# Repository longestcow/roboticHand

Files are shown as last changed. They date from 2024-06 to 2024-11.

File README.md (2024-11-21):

# Robotic Hand  
Robotics and Automation 30 major project, a computer-vision controlled robotic hand.  
All 3D parts were modelled with Autodesk Inventor.  

https://github.com/longestcow/roboticHand/assets/83398131/6dcfd66e-11ae-4421-9ee2-df73c73a6329

sketches relevant to the development process -  



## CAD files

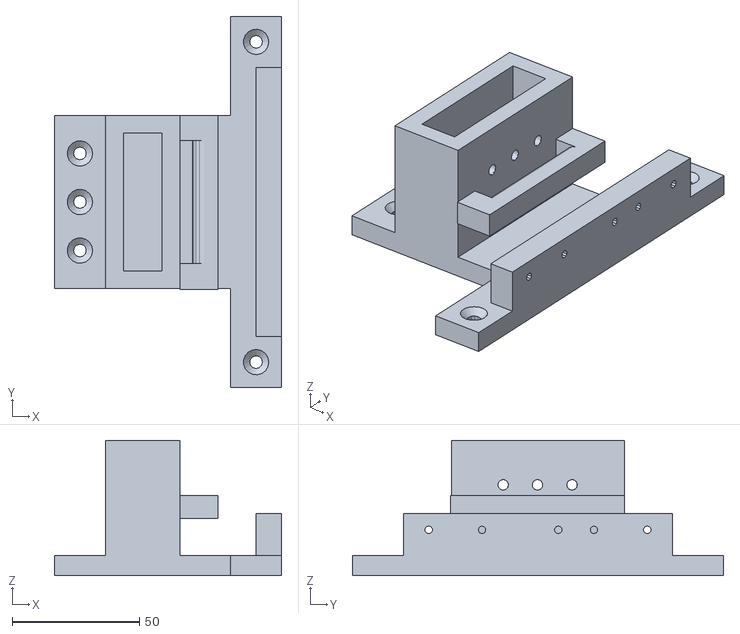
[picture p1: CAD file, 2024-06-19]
fingerModels/base.stl
89.3 x 146.0 x 53.2

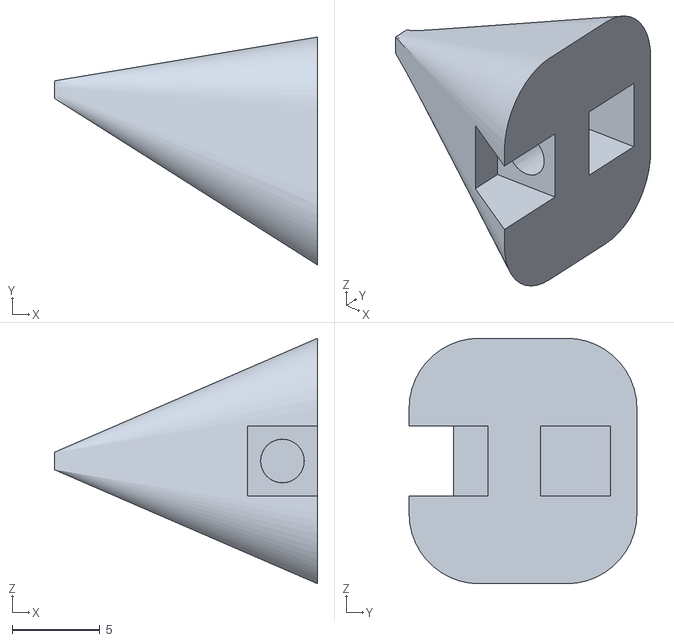
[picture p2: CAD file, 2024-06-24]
fingerModels/fingerCaps/pinkyCap.stl
15.0 x 13.0 x 14.0

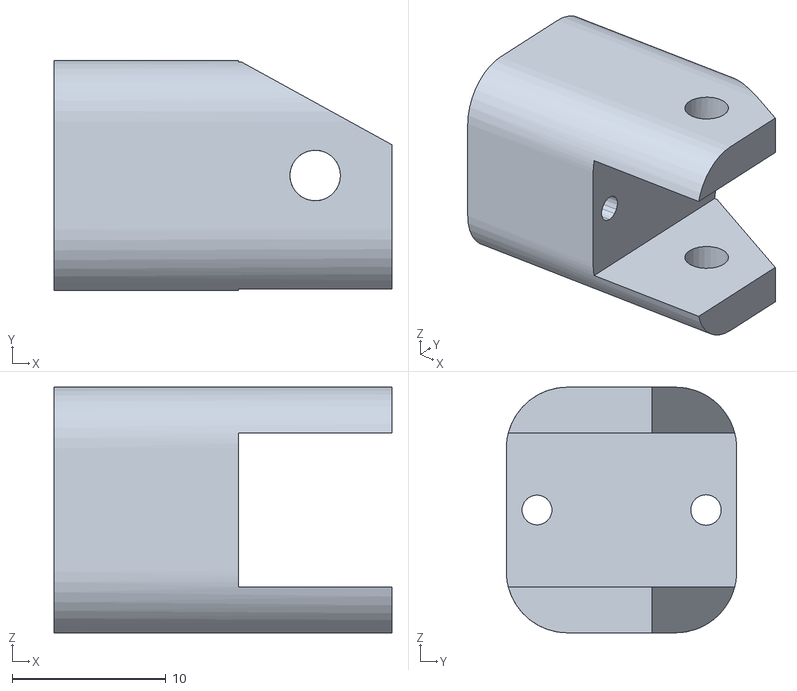
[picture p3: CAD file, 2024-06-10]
fingerModels/fingerIndexRing/stl/top.stl
22.0 x 15.0 x 16.0

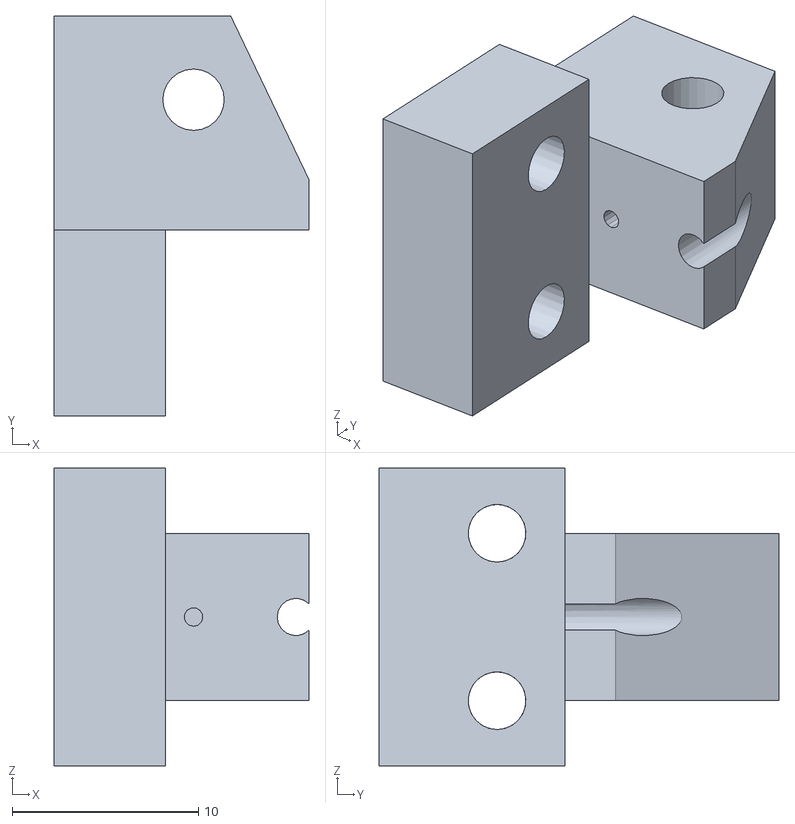
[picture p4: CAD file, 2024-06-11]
fingerModels/fingerMiddle/stl/mfMale.stl
13.7 x 21.5 x 16.0

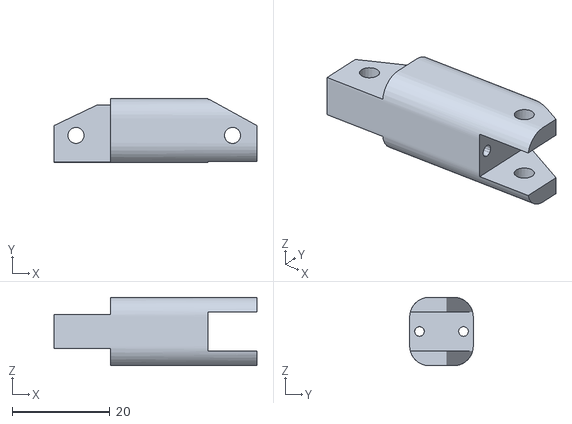
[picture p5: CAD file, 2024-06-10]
fingerModels/fingerPinky/stl/lower.stl
41.5 x 13.0 x 14.0

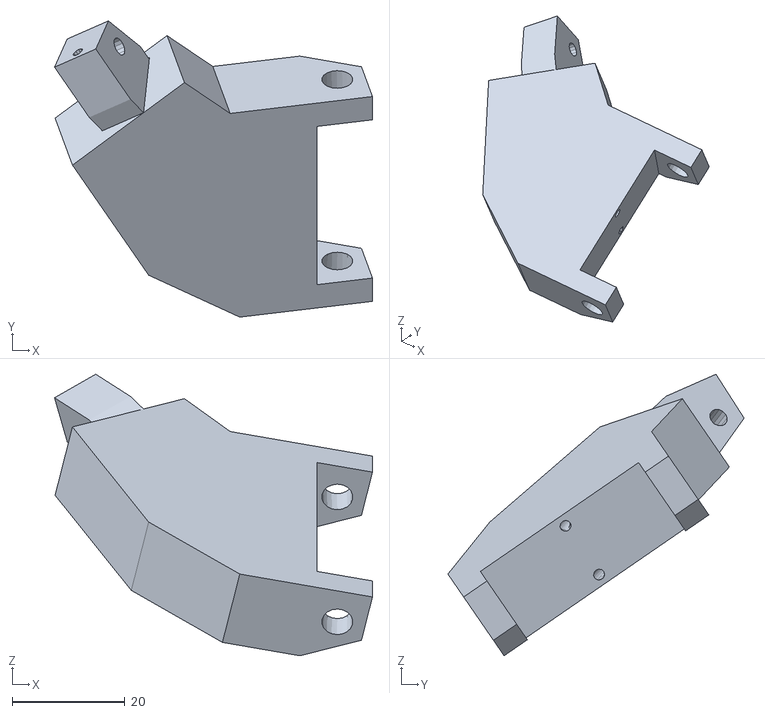
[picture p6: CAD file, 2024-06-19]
fingerModels/fingerThumb/stls/lowerThumb.stl
56.3 x 52.4 x 49.8

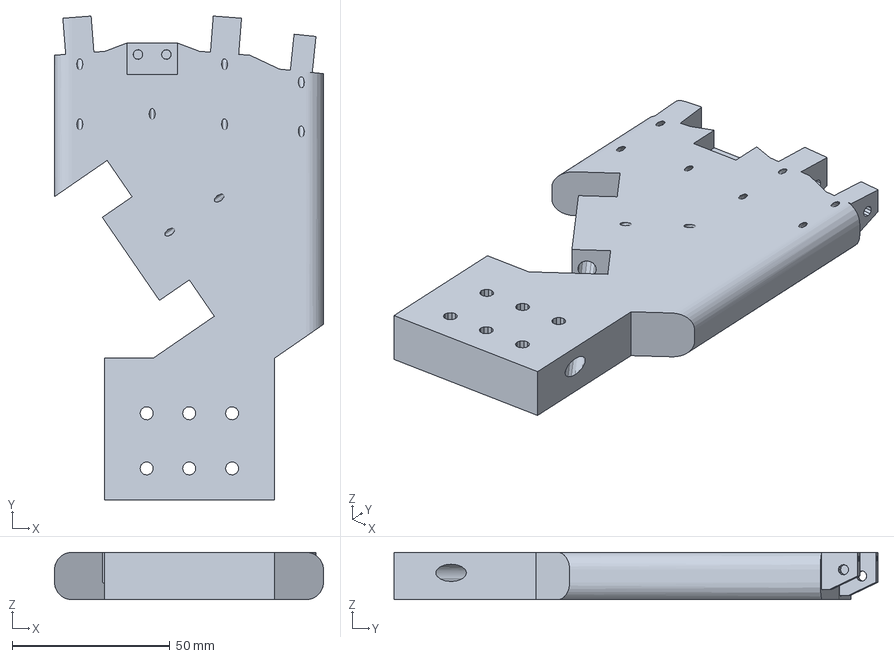
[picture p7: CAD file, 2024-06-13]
fingerModels/palm/palmWithConnectors.3mf
85.4 x 153.6 x 15.0 mm

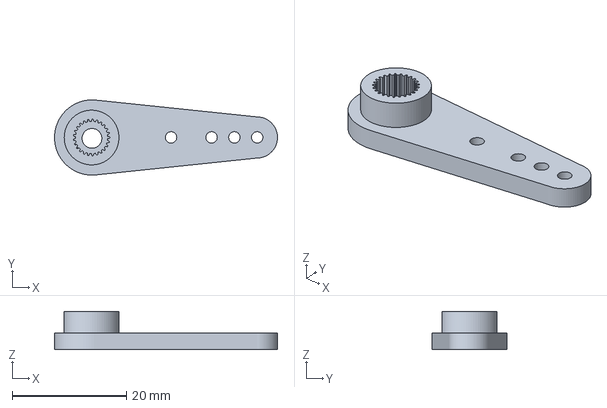
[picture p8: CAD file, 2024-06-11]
Servo_Arm.3mf
39.1 x 13.2 x 6.68 mm

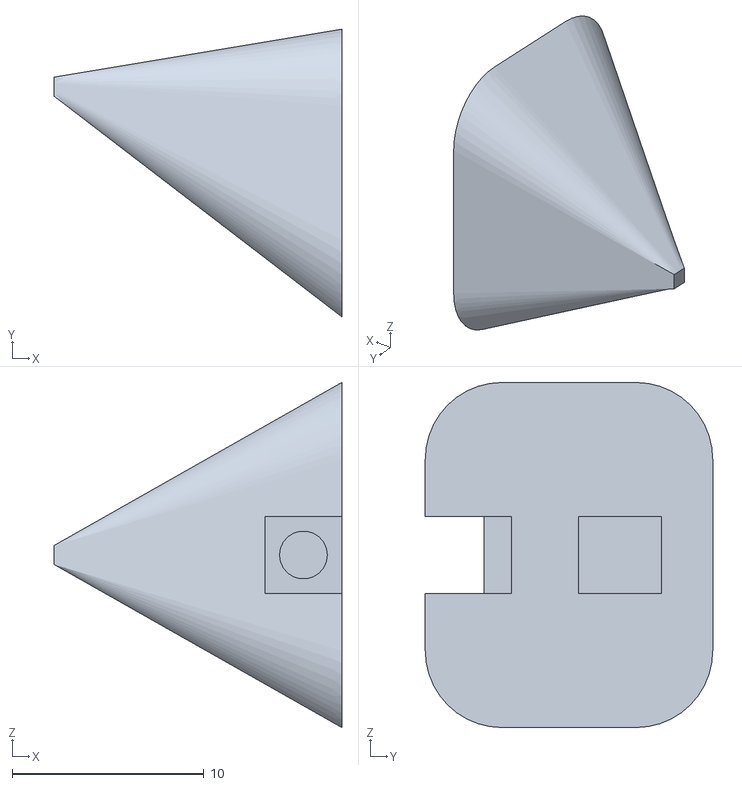
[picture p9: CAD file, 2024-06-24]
fingerModels/fingerCaps/thumbCap.stl
15.0 x 15.0 x 18.0

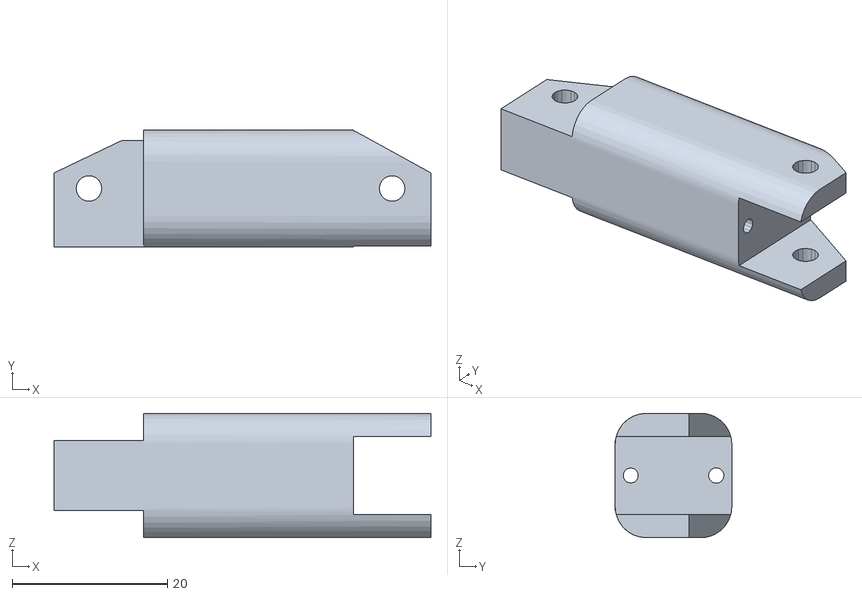
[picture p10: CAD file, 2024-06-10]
fingerModels/fingerIndexRing/stl/lower.stl
48.5 x 15.0 x 16.0

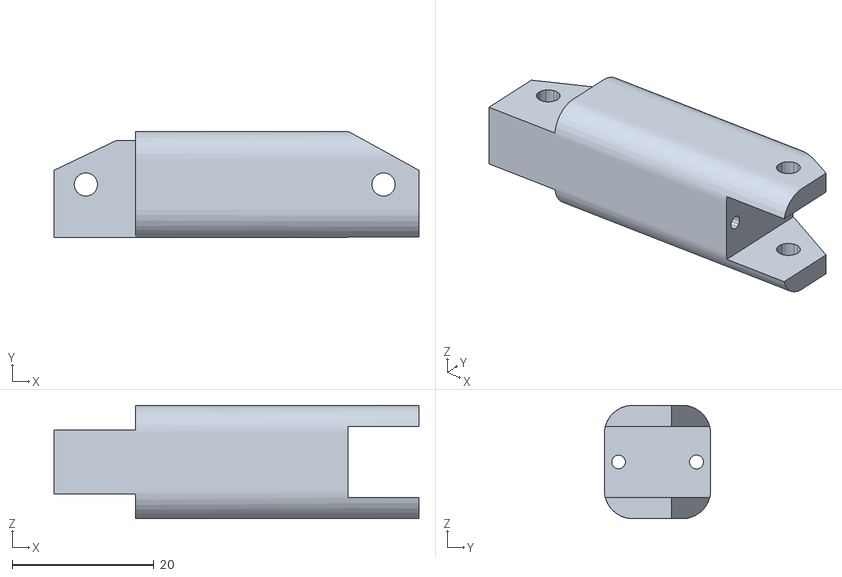
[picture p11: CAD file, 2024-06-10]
fingerModels/fingerMiddle/stl/lower.stl
51.5 x 15.0 x 16.0

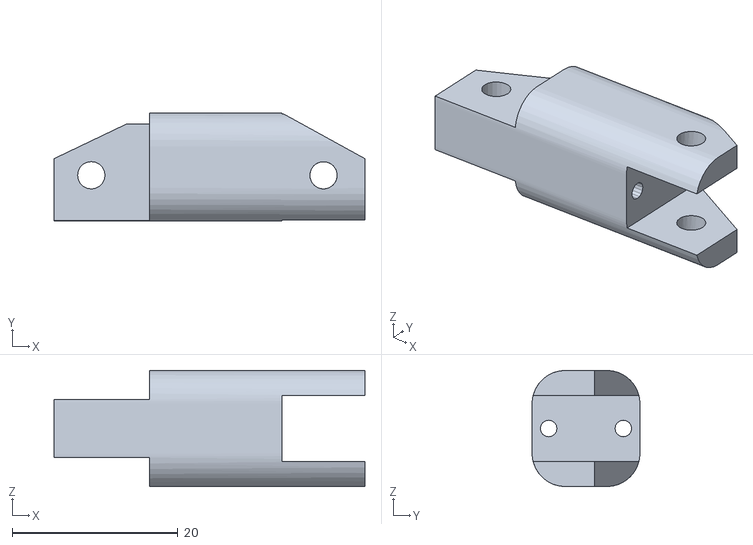
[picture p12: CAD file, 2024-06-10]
fingerModels/fingerPinky/stl/middle.stl
37.5 x 13.0 x 14.0

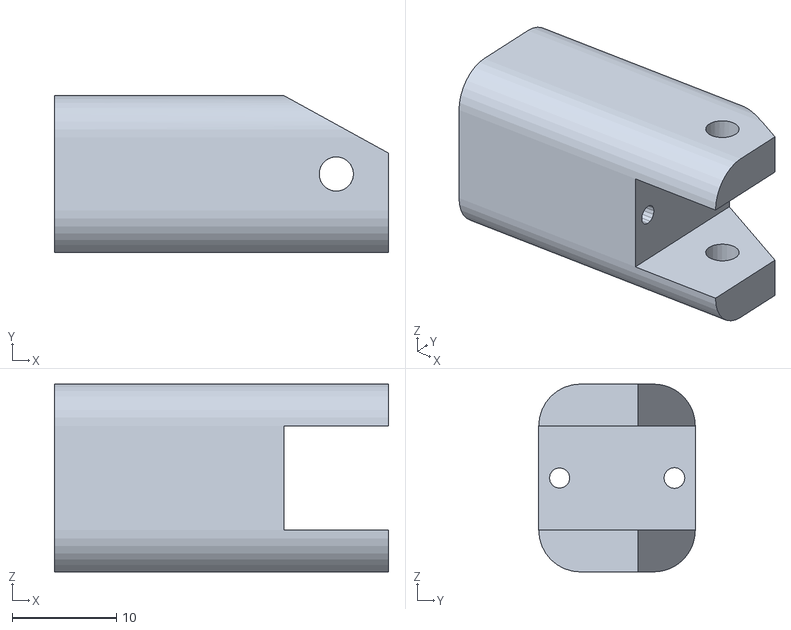
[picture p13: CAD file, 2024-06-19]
fingerModels/fingerThumb/stls/topThumb.stl
32.0 x 15.0 x 18.0

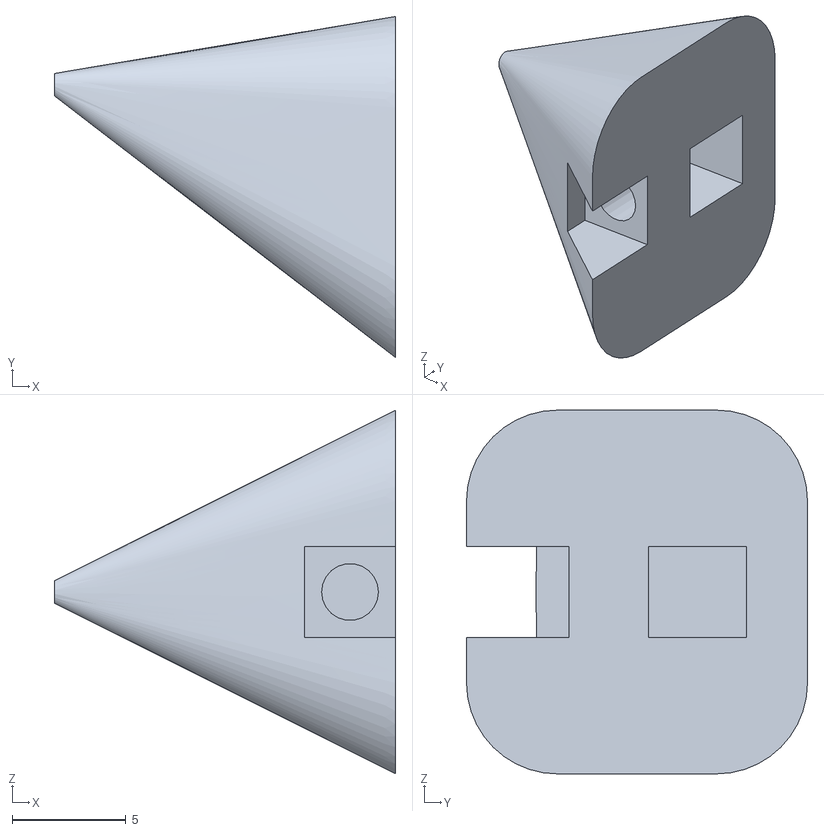
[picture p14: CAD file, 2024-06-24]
fingerModels/fingerCaps/middleIndexRingCap.stl
15.0 x 15.0 x 16.0

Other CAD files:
fingerModels/fingerIndexRing/stl/middle.stl
fingerModels/fingerPinky/stl/top.stl
fingerModels/fingerThumb/stls/middleThumb.stl
OldVersions/baseFingerLayout.0002.ipt
OldVersions/palm.0001.ipt
fingerIndexRing/middle.ipt
fingerModels/OldVersions/base.0004.ipt
fingerModels/OldVersions/baseFingerLayout.0001.ipt
fingerModels/OldVersions/handAssembly.0014.iam
fingerModels/OldVersions/mfMale.0004.ipt
fingerModels/OldVersions/mfP2.0002.iam
fingerModels/OldVersions/middleFingerMale.0001.ipt
fingerModels/OldVersions/middleMale.0001.iam
fingerModels/OldVersions/normMale.0002.ipt
fingerModels/OldVersions/palm.0022.ipt
fingerModels/OldVersions/pinkyMale.0003.ipt
fingerModels/OldVersions/thumbFemale.0001.ipt
fingerModels/OldVersions/thumbMale.0003.ipt
fingerModels/base.ipt
fingerModels/fingerIndexRing/OldVersions/lower.0007.ipt
fingerModels/fingerIndexRing/OldVersions/middle.0004.ipt
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

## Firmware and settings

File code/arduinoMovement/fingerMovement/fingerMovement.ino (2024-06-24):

#include <Servo.h>

String input = "default"; char var;

char fingers[] = "00000"; //contains the latest input from python
char cfingers[] = "00000"; //contains the current finger positions on the robot
int off[] = {0,180,180,0,0};
int on[] = {130,50,50,130,120};
//confirmed 11111
Servo servos[5];

void setup() {
  for(int i = 0; i<5; i++){
    servos[i].attach(i+2);
  }
  Serial.begin(9600);
  for(int i = 0; i<5; i++){
    servos[i].write(off[i]);
  }
}

void loop() {
  if (Serial.available() > 0) {
    input="";
    while(Serial.available() > 0) {
      var=(char) Serial.read();
      input+=var;
      delay(10);
    }
    input.trim();
    
    for(int i = 0; i<5; i++){
      fingers[i]=input.charAt(i);
    }
    
  }

  for(int i = 0; i<5; i++){
      if(fingers[i] != cfingers[i]){ 
        if(fingers[i]=='0'){
          servos[i].write(off[i]);
          cfingers[i]='0';
        }
        else {
          servos[i].write(on[i]);
          cfingers[i]='1';
        }
      }
  }
  
}

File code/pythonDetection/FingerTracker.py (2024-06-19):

import math

import cv2
import mediapipe as mp
import serial
import schedule

MIN_DISTANCE = 50
prevs = ""
distances = []


# https://colab.research.google.com/github/googlesamples/mediapipe/blob/main/examples/hand_landmarker/python/hand_landmarker.ipynb
class handDetector:
    def __init__(self, detCon=0.5, trackCon=0.5):
        self.results = None
        self.detCon = detCon
        self.trackCon = trackCon
        self.mpHands = mp.solutions.hands
        self.hands = self.mpHands.Hands(False, 1, 1, self.detCon, self.trackCon)
        self.mpDraw = mp.solutions.drawing_utils

    def findHand(self, image):
        imgRGB = cv2.cvtColor(image, cv2.COLOR_BGR2RGB)
        self.results = self.hands.process(imgRGB)
        landmarks = []
        dists = []
        if self.results.multi_hand_landmarks:
            hand = self.results.multi_hand_landmarks[0]

            self.mpDraw.draw_landmarks(image, hand, self.mpHands.HAND_CONNECTIONS,  # drawing onto image
                                       self.mpDraw.DrawingSpec(color=(0, 10, 200), thickness=2, circle_radius=4),
                                       self.mpDraw.DrawingSpec(color=(23, 23, 23), thickness=4))

            if len(hand.landmark) < 21:
                return []

            for id, lm in enumerate(hand.landmark):
                h, w, c = image.shape
                cx, cy = int(lm.x * w), int(lm.y * h)
                if id == 4 or id == 5 or id == 9 or id == 13 or id == 17:
                    landmarks.append([cx, cy])

                if id == 8 or id == 12 or id == 16 or id == 20:
                    ocx, ocy = landmarks[int((id - 4) / 4)]
                    dists.append(math.hypot(ocx - cx, ocy - cy) < MIN_DISTANCE)

                if id == 20:  # thumb
                    cx, cy = landmarks[0]
                    for i in range(1, 5):
                        ocx, ocy = landmarks[i]
                        if math.hypot(ocx - cx, ocy - cy) < MIN_DISTANCE:
                            dists.insert(0, True)
                            break
                    else:
                        dists.insert(0, False)

        return dists


def sendData(ard):
    global prevs
    if not distances:
        return
    s = ''.join(['1' if value else '0' for value in distances])
    if s == prevs:
        return
    print(s)

    ard.write(s.encode())
    prevs = s


if __name__ == "__main__":

    video = cv2.VideoCapture(0)
    video.set(3, 1280)
    video.set(4, 720)

    handDetector = handDetector()

    arduino = serial.Serial('COM10', 9600, write_timeout=0)
    schedule.every(1).seconds.do(sendData, arduino)

    while True:
        schedule.run_pending()

        success, img = video.read()
        distances = handDetector.findHand(img)

        cv2.imshow('omb', cv2.flip(img, 1))
        cv2.waitKey(1)

        if cv2.getWindowProperty('omb', cv2.WND_PROP_VISIBLE) < 1:
            break

    cv2.destroyAllWindows()

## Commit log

2024-06-02 init commit
    [baseFingerLayout.ipt]
2024-06-04 python to arduino
2024-06-05 palm and i/r finger models
    [baseFingerLayout.0002.ipt, baseFingerLayout.ipt, lower.ipt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]
2024-06-06 changes to finger models
    [fingerIndexRingSettings.3mf, lower.ipt, middle.ipt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]
2024-06-07 major code stuff
    finger "tracking" works now, data is somewhat sent from python to arduino (although still buggy)
    thumb tracking is also buggy
    [FingerTracker.py, fingerMovement.ino]
2024-06-07 finger model updates
    [lower.0002.ipt, middle.0003.ipt, palm.0001.ipt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]
2024-06-10 4 fingers + palm base + full hand assembly
    [baseFingerLayout.0001.ipt, baseFingerLayout.ipt, fingerIndexRingSettings.3mf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]
2024-06-10 palm changes
    [palm.0009.ipt, palm.0010.ipt, palm.ipt]
2024-06-11 a bunch of models
    [handAssembly.0001.iam, handAssembly.0008.iam, handAssembly.iam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]
2024-06-11 thumb connector stls
    [thumbFemale.stl, thumbMale.0003.ipt, thumbMale.0004.ipt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]
2024-06-12 thumb connectors changes
    [thumbFemale.0002.ipt, thumbFemale.0004.ipt, thumbFemale.ipt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]
2024-06-12 thumb connector changes
    [handAssembly.0009.iam, handAssembly.0011.iam, handAssembly.iam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]
2024-06-13 palm with connectors
    [handAssembly.0011.iam, handAssembly.0012.iam, handAssembly.iam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]
2024-06-17 base start
    [base.0001.ipt, base.ipt]
2024-06-18 base model + servo bracket
    [base.0001.ipt, base.0003.ipt, base.ipt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]
2024-06-18 floor thickness change
    [base.0003.ipt, base.0004.ipt, base.ipt]
2024-06-24 servo angles
